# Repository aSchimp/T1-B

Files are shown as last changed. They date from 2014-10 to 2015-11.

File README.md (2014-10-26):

T1-B
====

T1-B = Turtle Bot 1

Installation
====

This *must* be run on a BeagleBone Black running the Debian operating system.  Get the latest image from: http://beagleboard.org/latest-images. The image used for testing was dated 2014-04-23. To check the version installed use

````
cat /boot/uboot/ID.txt
````

Make sure you can establish an SSH connection to the BeagleBone Black. Also make sure that the BBB has a persistant internet connection, either through an ethernet connection or through a USB connection to your computer.

### Setting up a persistant USB internet connection

The steps below are for Windows.

* Open the control panel, and search for "network connections" in the search box. Click "View Network Connections" in the results.
* Right-click the internet connection to share with the BeagleBone Black and select Properties. Navigate to the Sharing tab.
* Select the option to "Allow other network users to connect through this computer's Internet connection"
* Select the BeagleBone Black's network connection from the dropdown and then click OK.
* Now go back to Network Connections and right click the BeagleBone Black's network connection, and select Properties.
* Click "Internet Protocol Version 4 (TCP/IPv4)" in the list and select Properties
* Select the options to "Obtain an IP address automatically" and "obtain DNS server address automatically", and click OK

On the BeagleBone Black run the following commands

````
route add default gw 192.168.7.1
echo "nameserver 8.8.8.8" >> /etc/resolv.conf
````

Test the connection by running `ping google.com`.

Run the following command.

````
nano /opt/scripts/boot/am335x_evm.sh
````

Scroll down until you see the following lines

````
/sbin/ifconfig usb0 192.168.7.2 netmask 255.255.255.252
/usr/sbin/udhcpd -S /etc/udhcpd.conf
````

Immediately after those lines, add the following:

````
/sbin/route add default gw 192.168.7.1 metric 1
````

While you're editing that file, add the following line as well (beneath the line just added). This will allow the WiFi connection which will be setup by the installation script to work on startup. Replace 192.168.1.1 with the IP address of your router. You can find this by running `ipconfig` from a command prompt in Windows. Look for the default gateway for the wireless network connection.

````
/sbin/route add default gw 192.168.1.1 metric 2
````

Thanks to [Carl Lance](http://lanceme.blogspot.com/2013/06/windows-7-internet-sharing-for.html) for the pointers on getting this to work.

### Optionally Disable HDMI

TODO: Add an explanation here

https://learn.adafruit.com/setting-up-wifi-with-beaglebone-black/hardware

### Install Git

````
ntpdate -b -s -u pool.ntp.org
apt-get update && apt-get install git
````

### Install T1-B Software

Shutdown the BBB and plug in the USB wifi adapter. Use a WiFi adapter from [this list](http://www.elinux.org/Beagleboard:BeagleBoneBlack#WIFI_Adapters) for best results. The T1-B installation script has only been tested with the [NETGEAR N150 Wi-Fi USB Adapter (WNA1100)](http://www.amazon.com/gp/product/B0036R9XRU/ref=oh_aui_detailpage_o02_s00?ie=UTF8&psc=1). Turn the device back on.

Clone this repository into {TODO: determine best directory} using the following command.

````
cd {TODO: put directory here}
git clone https://github.com/aschimp/t1-b
````

Place your WiFi network SSID and password into the settings.cfg file.

````
cd t1-b/setup
nano settings.cfg
````

Finally, run the install script. The system will reboot several times during the installation. Log messages after rebooting will be sent to the install_log.txt file in the t1-b/setup directory.

````
chmod +x *.sh
./install.sh
````

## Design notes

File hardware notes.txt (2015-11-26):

Fasteners for main circuit board
 - Nuts: DURATOOL   M2.5- HFST-Z100-  FULL NUT, STEEL, BZP, M2.5: http://www.newark.com/webapp/wcs/stores/servlet/ProductDisplay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
 - Top washers (between board and screw head): KEYSTONE     3114  FASTENERS, NYLON WASHER - external diameter: 4.75mm - inner diameter: 2.49mm - length: 0.81mm - http://www.newark.com/webapp/wcs/stores/servlet/ProductDisplay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
 - Spacer washers (between board and chassis): RAF ELECTRONIC HARDWARE  1124-8-N  SPACER, NYLON, 6.35MM X 6.35MM - inner diameter: 4.216MM: http://www.newark.com/webapp/wcs/stores/servlet/ProductDisplay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
 - Screws: DURATOOL     M2.512 PRSTMCZ100-  SCREW, POZI PAN, STEEL, M2.5X12: http://www.newark.com/webapp/wcs/stores/servlet/ProductDisplay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

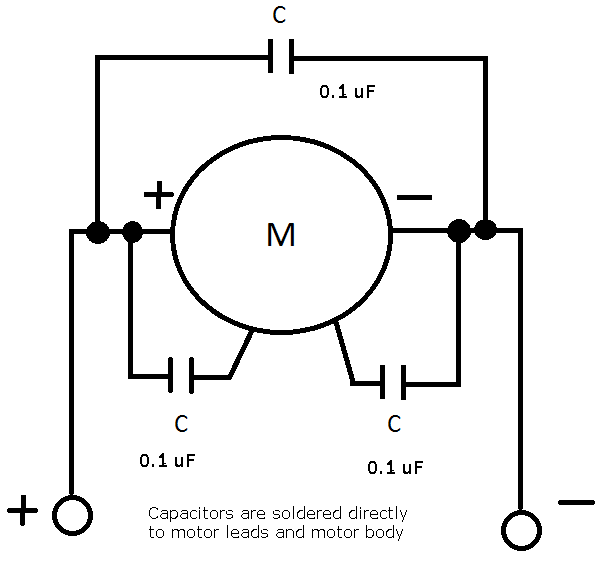
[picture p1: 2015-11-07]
eagle-t1-b/drive_motor.png

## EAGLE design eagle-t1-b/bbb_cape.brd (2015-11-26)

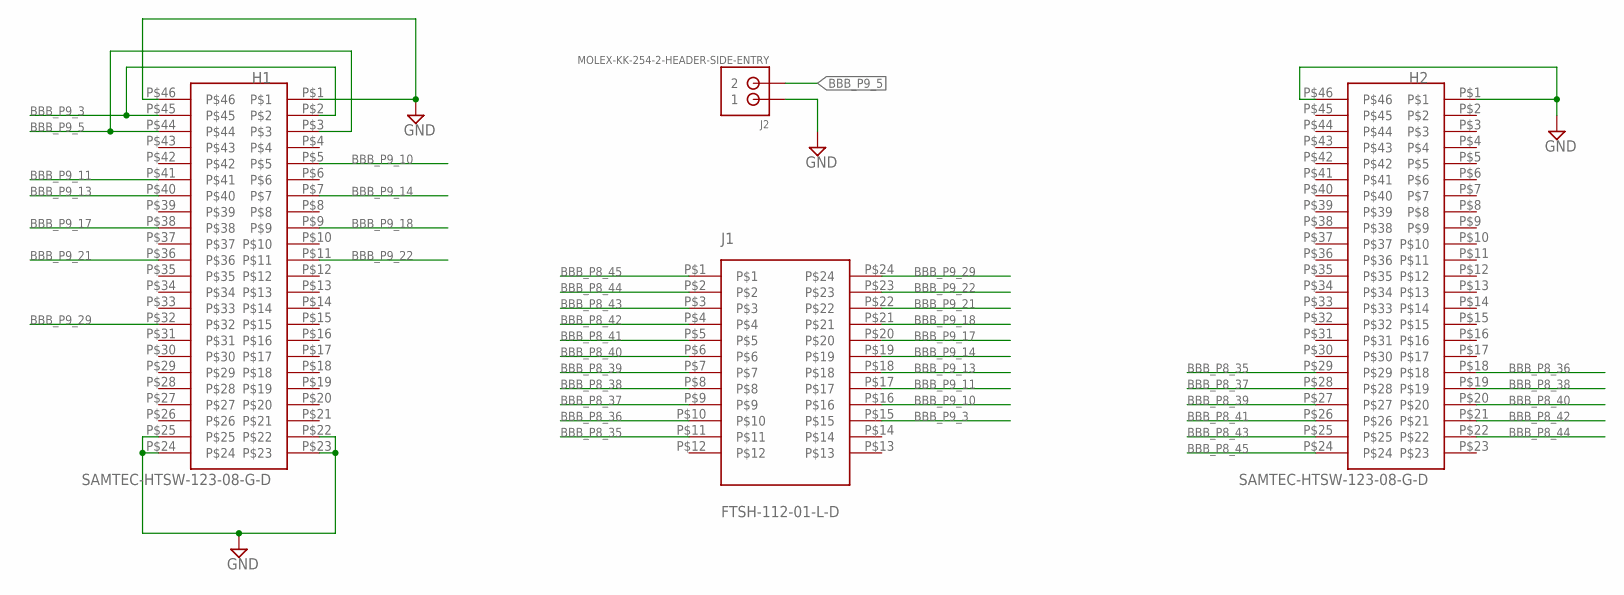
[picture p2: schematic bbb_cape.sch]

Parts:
H1, H2: SAMTEC-HTSW-123-08-G-D; HEADER-2X23-0.1-INCH
J1: FTSH-112-01-L-D
J2: MOLEX-KK-254-2-HEADER-SIDE-ENTRY

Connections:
BBB_P8_35: H2.P$29, J1.P$11
BBB_P8_36: H2.P$18, J1.P$10
BBB_P8_37: H2.P$28, J1.P$9
BBB_P8_38: H2.P$19, J1.P$8
BBB_P8_39: H2.P$27, J1.P$7
BBB_P8_40: H2.P$20, J1.P$6
BBB_P8_41: H2.P$26, J1.P$5
BBB_P8_42: H2.P$21, J1.P$4
BBB_P8_43: H2.P$25, J1.P$3
BBB_P8_44: H2.P$22, J1.P$2
BBB_P8_45: H2.P$24, J1.P$1
BBB_P9_3: H1.P$2, H1.P$45, J1.P$15
BBB_P9_5: H1.P$3, H1.P$44, J2.P$2 (2)
BBB_P9_10: H1.P$5, J1.P$16
BBB_P9_11: H1.P$41, J1.P$17
BBB_P9_13: H1.P$40, J1.P$18
BBB_P9_14: H1.P$7, J1.P$19
BBB_P9_17: H1.P$38, J1.P$20
BBB_P9_18: H1.P$9, J1.P$21
BBB_P9_21: H1.P$36, J1.P$22
BBB_P9_22: H1.P$11, J1.P$23
BBB_P9_29: H1.P$32, J1.P$24
GND: H1.P$1, H1.P$22, H1.P$23, H1.P$24, H1.P$25, H1.P$46, H2.P$1, H2.P$46, J2.P$1 (1)

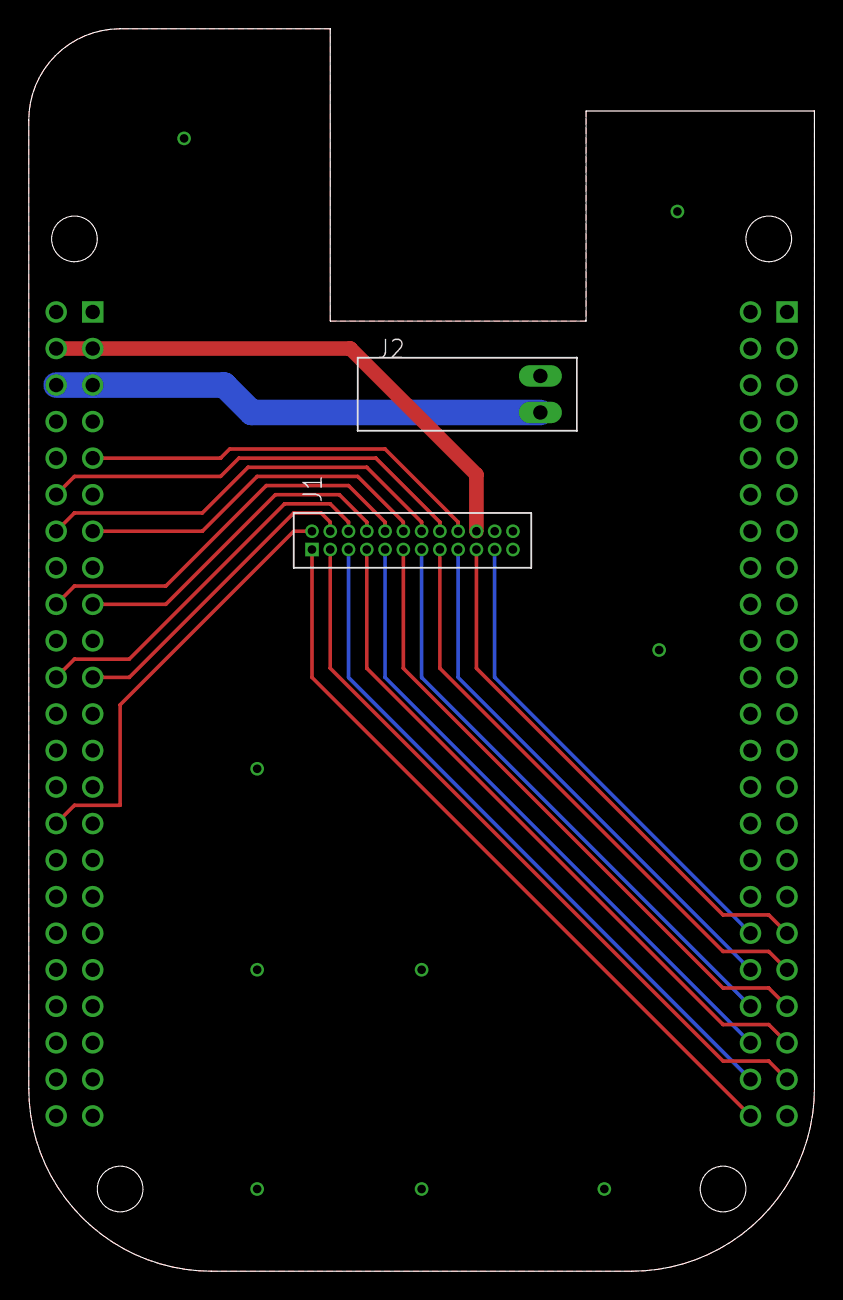
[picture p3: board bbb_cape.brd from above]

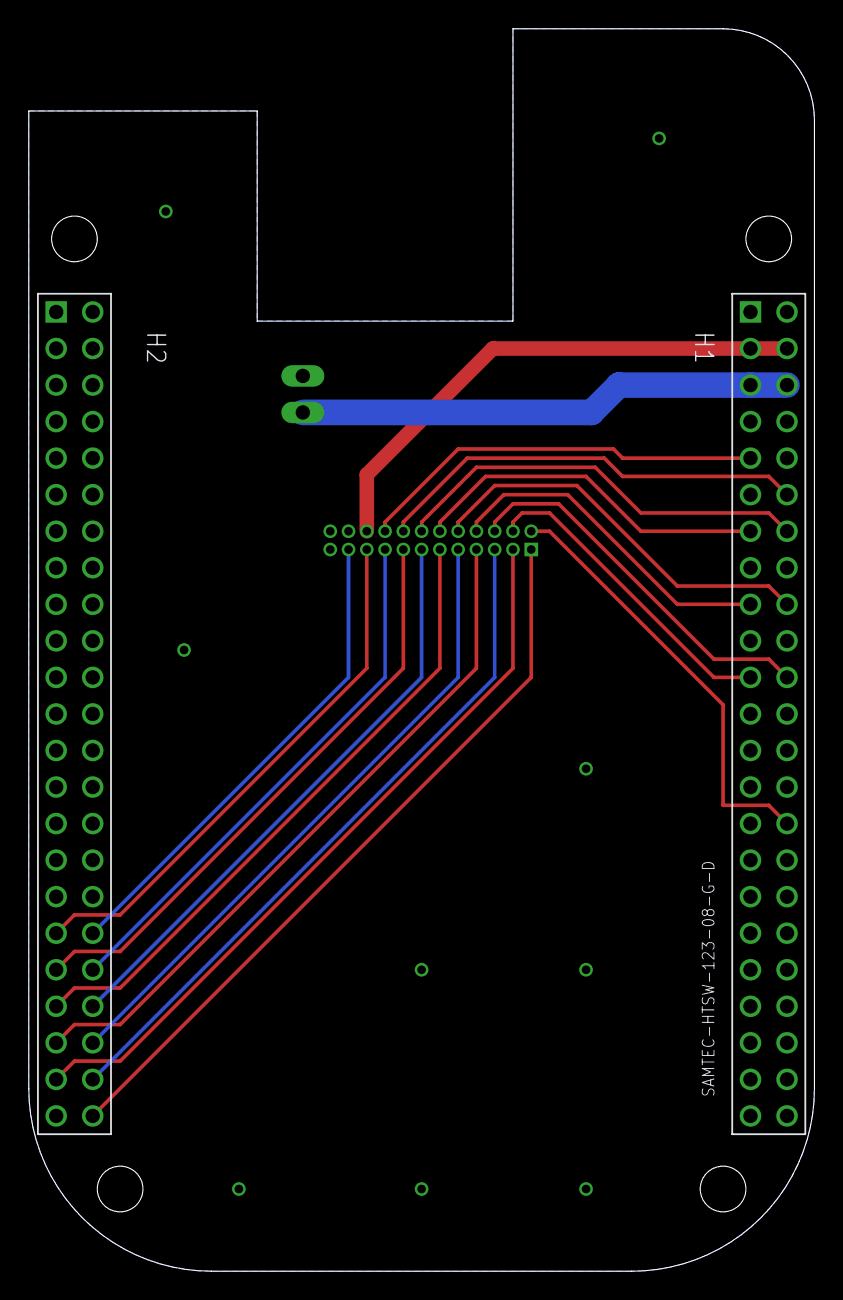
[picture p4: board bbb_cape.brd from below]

Board: 2 copper layers, 54.6 x 86.4 mm, 4 parts (2 on the bottom side), 23 nets.

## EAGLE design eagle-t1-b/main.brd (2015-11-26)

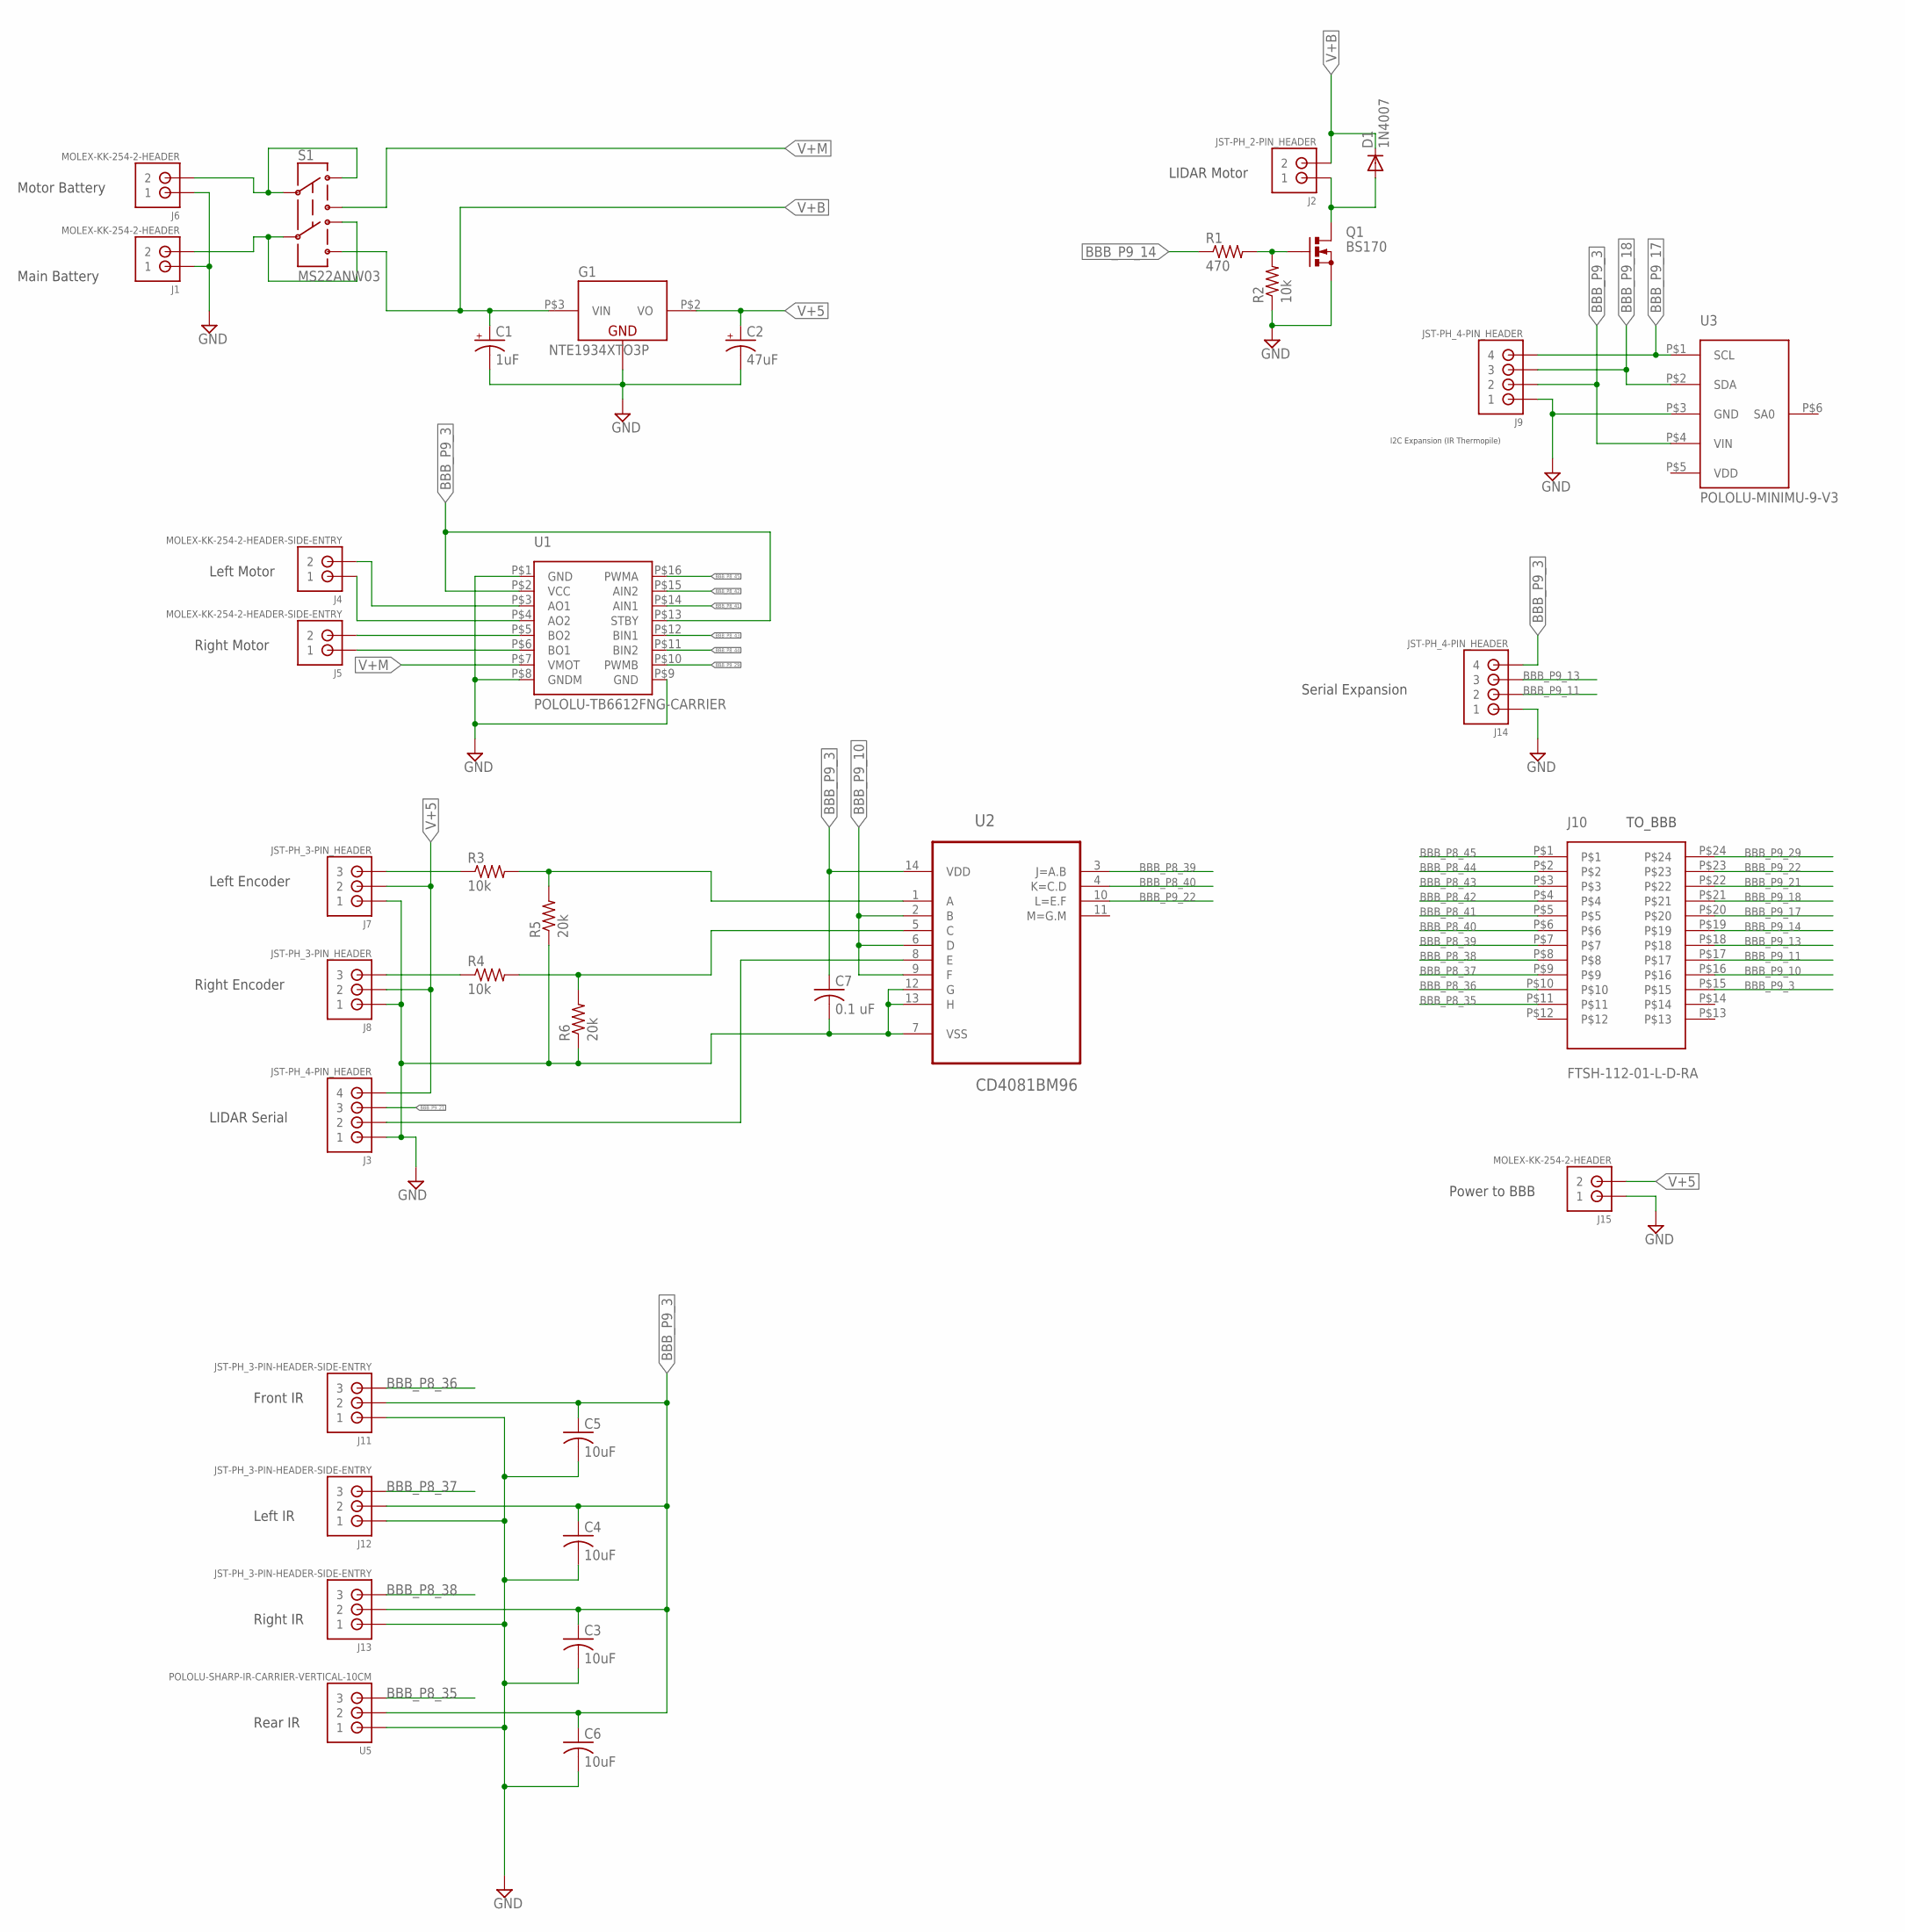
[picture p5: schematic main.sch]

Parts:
C1: 1uF; PANASONIC_B
C2: 47uF; PANASONIC_C
C3, C4, C5, C6: 10uF; C0603
C7: 0.1 uF; C0603
D1: 1N4007; DO41-10
G1: NTE1934XTO3P; TO3P
J1, J6, J15: MOLEX-KK-254-2-HEADER
J2: JST-PH_2-PIN_HEADER; JST_B2B-PH_HEADER
J3, J9, J14: JST-PH_4-PIN_HEADER; JST_B4B-PH_HEADER
J4, J5: MOLEX-KK-254-2-HEADER-SIDE-ENTRY
J7, J8: JST-PH_3-PIN_HEADER; JST_B3B-PH_HEADER
J10: FTSH-112-01-L-D-RA
J11, J12, J13: JST-PH_3-PIN-HEADER-SIDE-ENTRY; JST-S3B-PH-K-S
Q1: BS170; SOT54E
R1: 470; R0402
R2, R3, R4: 10k; R0402
R5, R6: 20k; R0402
S1: MS22ANW03; SWITCH-DPDT-NKK-MS22ANW03
U1: POLOLU-TB6612FNG-CARRIER
U2: CD4081BM96; SO14
U3: POLOLU-MINIMU-9-V3
U5: POLOLU-SHARP-IR-CARRIER-VERTICAL-10CM; POLOLU-SHARP-IR-CARRIER-VERTICAL-GP2Y0D8**Z0F

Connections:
BBB_P8_35: J10.P$11, U5.P$3 (3)
BBB_P8_36: J10.P$10, J11.P$3 (3)
BBB_P8_37: J10.P$9, J12.P$3 (3)
BBB_P8_38: J10.P$8, J13.P$3 (3)
BBB_P8_39: J10.P$7, U2.3 (J=A.B)
BBB_P8_39_AND_INPUT: R3.2, R5.2, U2.1 (A)
BBB_P8_40: J10.P$6, U2.4 (K=C.D)
BBB_P8_40_AND_INPUT: R4.2, R6.2, U2.5 (C)
BBB_P8_41: J10.P$5, U1.P$14 (AIN1)
BBB_P8_42: J10.P$4, U1.P$15 (AIN2)
BBB_P8_43: J10.P$3, U1.P$12 (BIN1)
BBB_P8_44: J10.P$2, U1.P$11 (BIN2)
BBB_P8_45: J10.P$1, U1.P$16 (PWMA)
BBB_P9_3: C3.1, C4.1, C5.1, C6.1, C7.1, J9.P2 (2), J10.P$15, J11.P$2 (2), J12.P$2 (2), J13.P$2 (2), J14.P4 (4), U1.P$2 (VCC), U1.P$13 (STBY), U2.14 (VDD), U3.P$4 (VIN), U5.P$2 (2)
BBB_P9_10: J10.P$16, U2.2 (B), U2.6 (D), U2.9 (F)
BBB_P9_11: J10.P$17, J14.P2 (2)
BBB_P9_13: J10.P$18, J14.P3 (3)
BBB_P9_14: J10.P$19, R1.1
BBB_P9_17: J9.P4 (4), J10.P$20, U3.P$1 (SCL)
BBB_P9_18: J9.P3 (3), J10.P$21, U3.P$2 (SDA)
BBB_P9_21: J3.P3 (3), J10.P$22
BBB_P9_22: J10.P$23, U2.10 (L=E.F)
BBB_P9_29: J10.P$24, U1.P$10 (PWMB)
GND: C1.-, C2.-, C3.2, C4.2, C5.2, C6.2, C7.2, G1.P$1 (GND), J1.P$1 (1), J3.P1 (1), J6.P$1 (1), J7.P1 (1), J8.P1 (1), J9.P1 (1), J11.P$1 (1), J12.P$1 (1), J13.P$1 (1), J14.P1 (1), J15.P$1 (1), Q1.S, R2.1, R5.1, R6.1, U1.P$1 (GND), U1.P$8 (GNDM), U1.P$9 (GND), U2.7 (VSS), U2.12 (G), U2.13 (H), U3.P$3 (GND), U5.P$1 (1)
unnamed: Q1.G, R1.2, R2.2
unnamed: D1.A, J2.P1 (1), Q1.D
unnamed: J5.P$1 (1), U1.P$6 (BO1)
unnamed: J5.P$2 (2), U1.P$5 (BO2)
unnamed: J4.P$1 (1), U1.P$4 (AO2)
unnamed: J4.P$2 (2), U1.P$3 (AO1)
unnamed: J7.P3 (3), R3.1
unnamed: J6.P$2 (2), S1.P$1 (1), S1.P$2 (2)
unnamed: J1.P$2 (2), S1.P$4 (4), S1.P$5 (5)
unnamed: J8.P3 (3), R4.1
unnamed: J3.P2 (2), U2.8 (E)
V+5: C2.+, G1.P$2 (VO), J3.P4 (4), J7.P2 (2), J8.P2 (2), J15.P$2 (2)
V+B: C1.+, D1.C, G1.P$3 (VIN), J2.P2 (2), S1.P$6 (6)
V+M: S1.P$3 (3), U1.P$7 (VMOT)
VDD: U3.P$5 (VDD)

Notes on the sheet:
Left Motor
Right Motor
Motor Battery
Main Battery
Left Encoder
Right Encoder
LIDAR Serial
LIDAR Motor
I2C Expansion (IR Thermopile)
TO_BBB
Serial Expansion
Front IR
Left IR
Right IR
Rear IR
Power to BBB

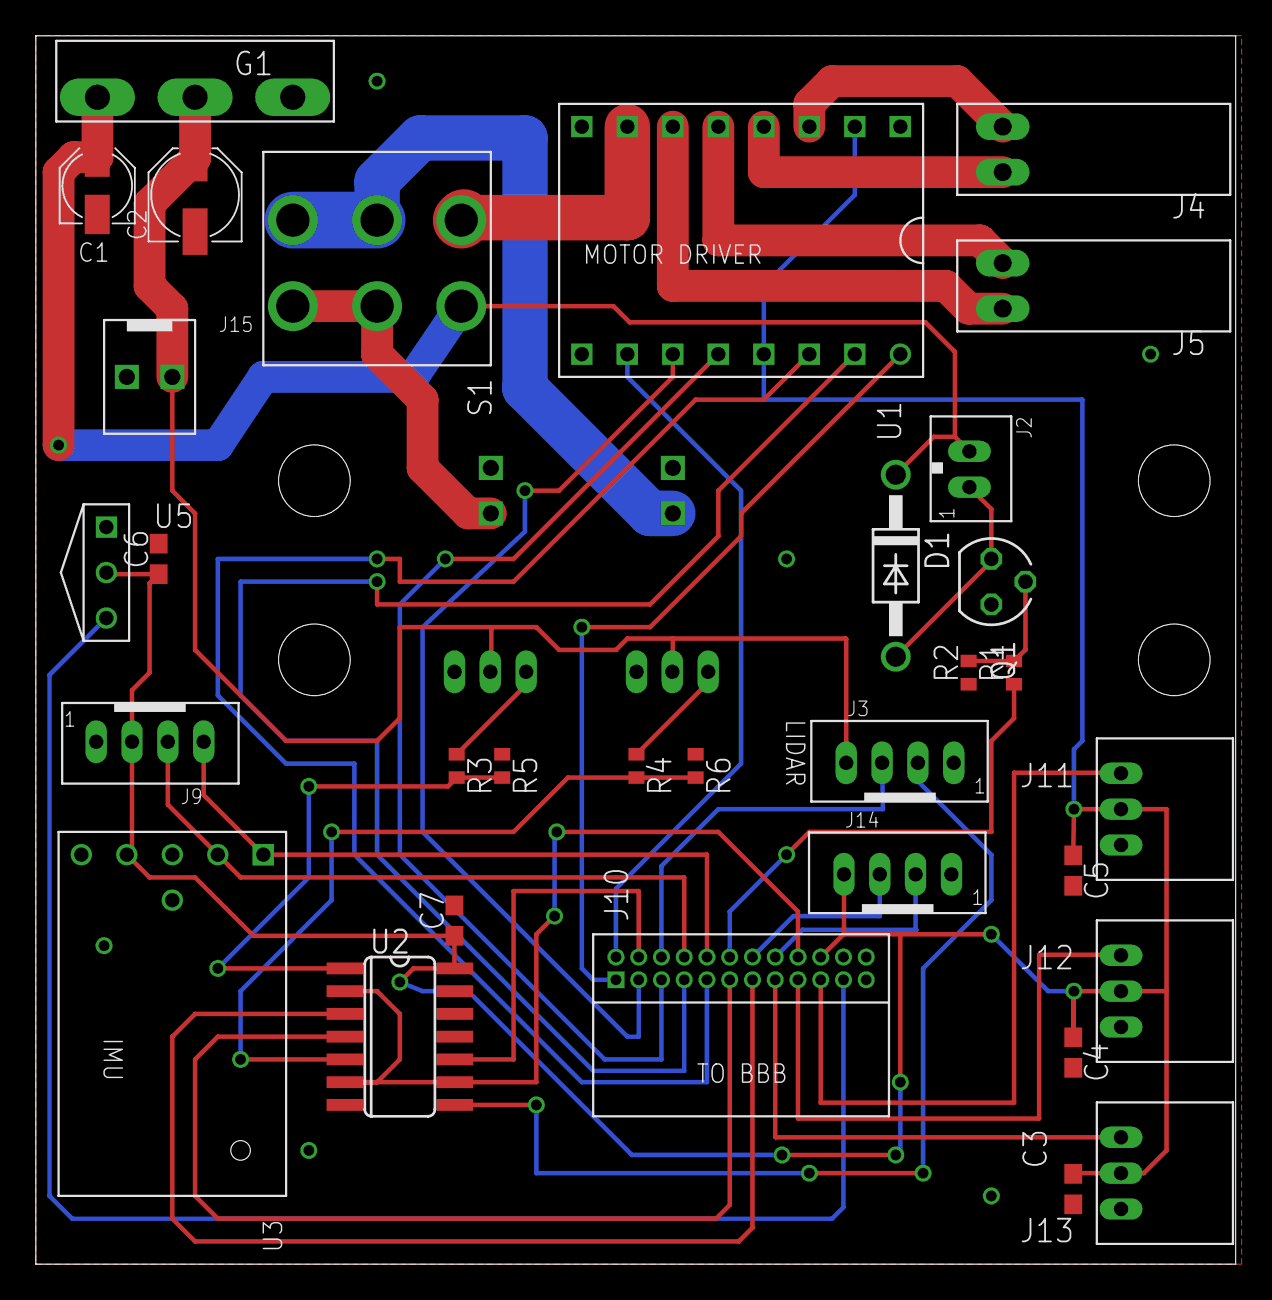
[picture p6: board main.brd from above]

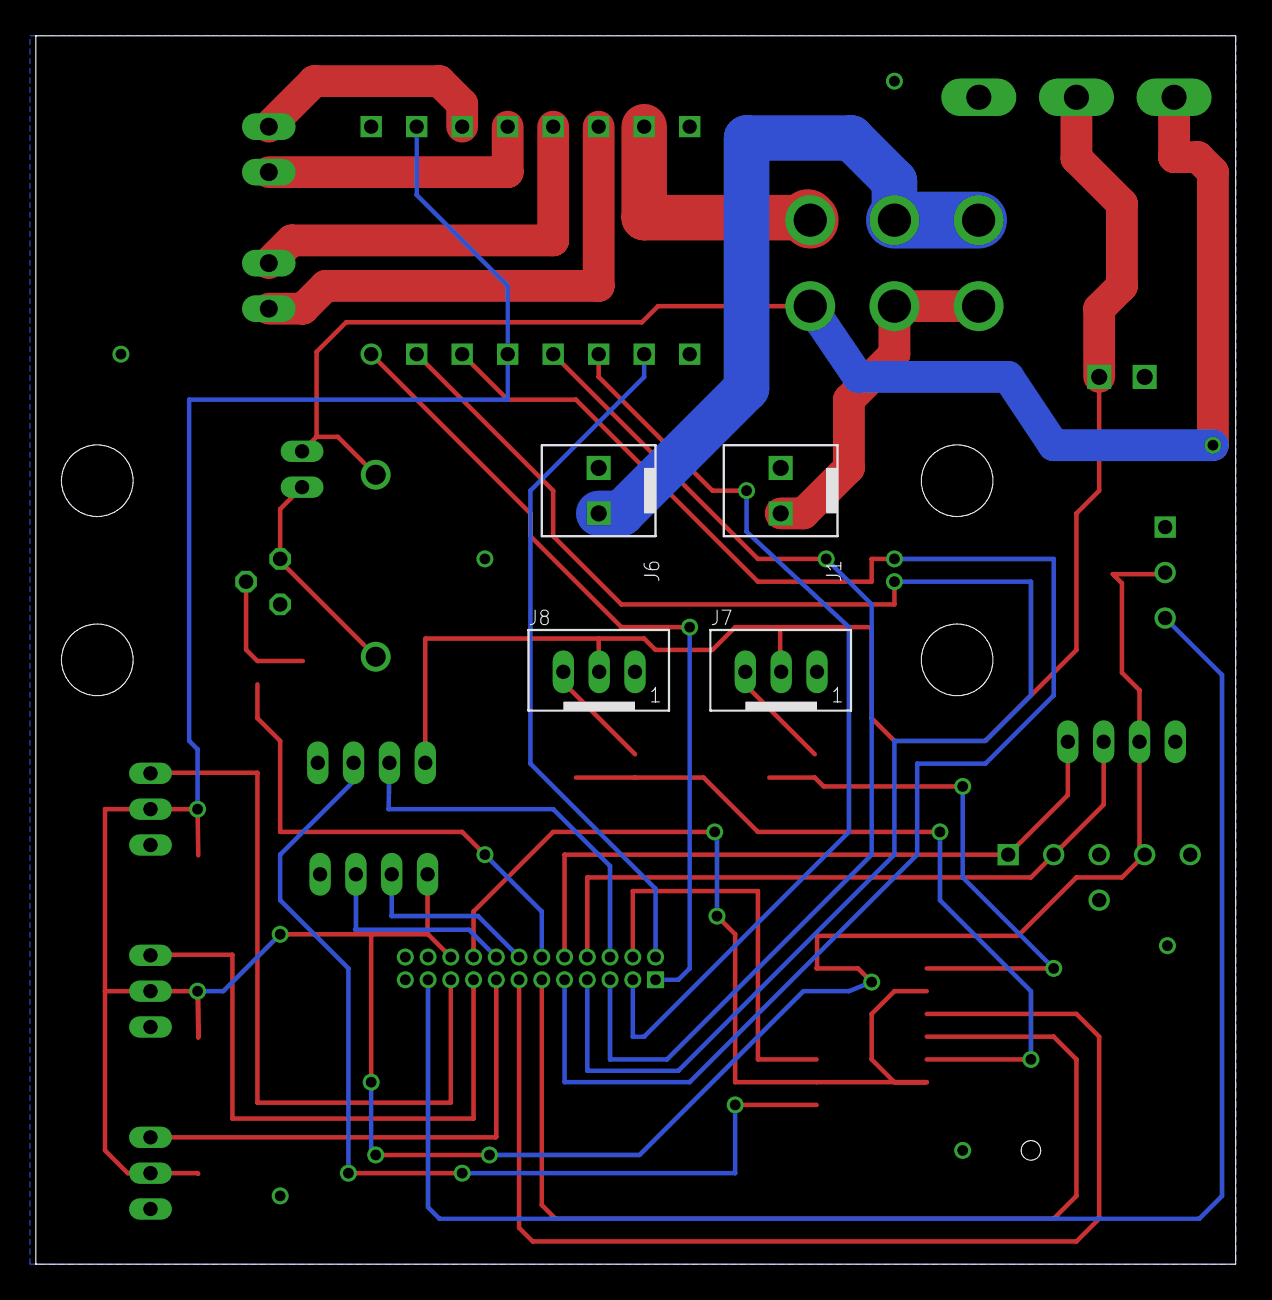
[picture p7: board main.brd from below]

Board: 2 copper layers, 67.0 x 68.6 mm, 36 parts (4 on the bottom side), 38 nets.

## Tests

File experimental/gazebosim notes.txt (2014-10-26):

upgraded to virtualbox 4.3.10 (upgraded guest additions in manager, then in vm)
http://askubuntu.com/a/22745/162919

add vboxvideo to /etc/modules file

sudo apt-get install mesa-utils, then run glxinfo

export LIBGL_ALWAYS_SOFTWARE=1  ------ this works, but is slow

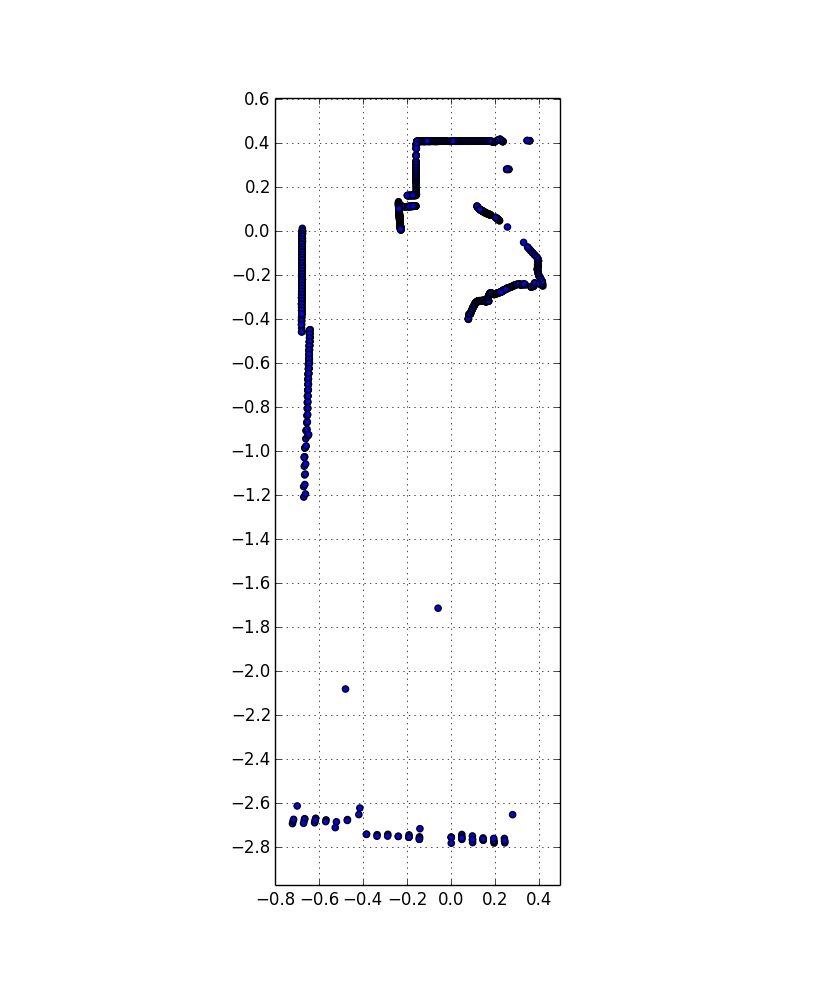
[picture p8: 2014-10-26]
experimental/first_lidar_test/lidar_graph_1.png

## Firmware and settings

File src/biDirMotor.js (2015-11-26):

var fs = require('fs');
var path = require('path');
var glob = require('glob');
var ioHelper = require('./ioHelper.js');

// constants
var dutyCycleMin = 0.1;
var dutyCycleMax = 0.7;
var period = 1000000;

// bi-directional motor
function BiDirMotor(pwmPath, gpio1Path, gpio2Path) {
    var self = this;
    self._pwmPath = pwmPath;
    self._gpio1Path = gpio1Path;
    self._gpio2Path = gpio2Path;

    self.setRotation(0);
}

// The value should be a number between -1 and 1. Negative values cause CW rotation and positive values cause CCW rotation. A value of 0 stops the motor. The absolute value controls the pwm duty cycle (speed).
BiDirMotor.prototype.setRotation = function(value) {
    var self = this;

    if (value === 0) {
        ioHelper.setGpioSignal(self._gpio1Path, 0);
        ioHelper.setGpioSignal(self._gpio2Path, 0);
        ioHelper.sendPwmCommand(self._pwmPath, 'run', '0');
        return;
    }

    var duty = Math.round((1 - Math.min(Math.max(Math.abs(value), dutyCycleMin), dutyCycleMax)) * period);
    ioHelper.sendPwmCommand(self._pwmPath, 'period', period.toString());
    ioHelper.sendPwmCommand(self._pwmPath, 'duty', duty.toString());
    ioHelper.sendPwmCommand(self._pwmPath, 'run', '1');

    if (value > 0) {
        ioHelper.setGpioSignal(self._gpio1Path, 1);
        ioHelper.setGpioSignal(self._gpio2Path, 0);
    }
    else if (value < 0) {
        ioHelper.setGpioSignal(self._gpio1Path, 0);
        ioHelper.setGpioSignal(self._gpio2Path, 1);
    }
};

module.exports = BiDirMotor;

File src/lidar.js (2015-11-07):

var util = require('util');
var events = require('events');
var SerialPort = require("serialport").SerialPort;
var ioHelper = require('./ioHelper.js');

function LidarPacket(index, speed, dist1, dist2, dist3, dist4){
    this.index = index;
    this.speed = speed;
    this.dist1 = dist1;
    this.dist2 = dist2;
    this.dist3 = dist3;
    this.dist4 = dist4;
}

/**
 * Computes and returns the checksum as an int.
 * @param {Array} data - The data to compute the checksum for. Must be 20 bytes.
 * @return {Number} The checksum as an integer.
 */
var computeChecksum = function(data) {
    // group the data by word, little-endian
    var dataList = [];
    for (var i = 0; i < 10; i++){
        dataList.push(data[2*i] + (data[2*i+1]<<8));
    }

    // compute the checksum on 32 bits
    var chk32 = 0;
    dataList.forEach(function(item){
        chk32 = (chk32 << 1) + item;
    });

    // return a value wrapped around on 15 bits, and truncated to still fit into 15 bits
    var checksum = (chk32 & 0x7FFF) + (chk32 >> 15); // wrap around to fit into 15 bits
    checksum = checksum & 0x7FFF; // truncate to 15 bits
    return checksum;
};

/**
 * Gets the lidar distance reading from a 4 byte data section.
 * @param {Array} bytes - Buffer with 4 bytes of data.
 * @return {Number} The distance reading as an integer.
 */
var parsePacketDataSection = function(bytes) {
    // if the 8th bit of the byte 1 is set, the data is invalid; the 7th bit of byte 1 is a strength warning (varies with material sometimes) flag, but we are ignoring it for now
    if ((bytes[1] & 128) === 128)
        return -1;

    // check strength warning bit
    if ((bytes[1] & 64) === 64)
        return -2;

    // get distance from byte 0 and byte 1; byte 2 and byte 3 contain signal strength data, which we are ignoring for now
    return bytes[0] + ((bytes[1] & 63) << 8);
};

var parsePacket = function(bytes) {
    // first byte in the packet must be 0xFA
    if (bytes[0] != 0xFA)
        return null;

    // verify data via checksum
    if (computeChecksum(bytes.slice(0, 20)) !== (bytes[20] + (bytes[21] << 8)))
        return null;

    // packet index must be between 0xA0 and 0xF9
    var index = bytes[1];
    if (index < 0xA0 || index > 0xF9)
        return null;

    // adjust index to 0 based index
    index = index - 0xA0;

    // speed unit used by the LIDAR is in 64ths of an RPM; we want the speed in RPMs
    var speed = (bytes[2] + (bytes[3]<<8))/64.0;

    var distances = [];
    for (var i = 1; i < 5; i++)
        distances.push(parsePacketDataSection(bytes.slice(4*i, 4*i+4)));

    return new LidarPacket(index, speed, distances[0], distances[1], distances[2], distances[3]);
};

function Lidar(serialPath, pwmPath) {
    var self = this;
    self._pwmPath = pwmPath;
    self._lidarStopped = true;
    self._pwmDuty = 710000;
    self._serialPort = new SerialPort(serialPath, {
        baudrate: 115200
    });

    self._serialPort.on("open", function () {
        console.log('serial port to lidar is open');

        var currentPacketData = [];
        self._serialPort.on('data', function(data) {
            //console.log('data received from lidar: ' + data.toString('hex'));
            self.emit('raw data', data);

            for (var i = 0; i < data.length; i++) {
                var b = data[i];

                // if we're starting a new packet, but the current byte doesn't mark the beginning of the packet, skip it
                if (currentPacketData.length === 0 && b != 0xFA)
                    continue;

                currentPacketData.push(b);

                if (currentPacketData.length === 22) {
                    var packet = parsePacket(currentPacketData);
                    if (packet === null) {
                        // packet was invalid; check for 0xFA packet start marker in the last packet, as sometimes some bytes are dropped and the next packet is already started
                        var nextIndex = currentPacketData.slice(1).indexOf(0xFA) + 1;
                        if (nextIndex > 0)
                            currentPacketData = currentPacketData.slice(nextIndex);
                        else
                            currentPacketData = [];
                    }
                    else {
                        self.emit('packet', packet);

                        // reset currentPacketData
                        currentPacketData = [];
                    }
                }
            }
        });
    });

    var targetRPM = 240;
    var lastRPM = 0
    var rpmAdjustInProgress = false;
    self.on('packet', function(packet) {

        if (packet.index != 0 || self._lidarStopped){
            return;
        }

        var rpm = packet.speed;
        var prevRPM = 0;

        if (rpm > 100 && (rpm < targetRPM - 5 || rpm > targetRPM + 5) && lastRPM > 0 && Math.abs(rpm - lastRPM) < 3 && !rpmAdjustInProgress) {
            var deltaRPM = targetRPM - rpm;
            var deltaDuty = Math.round((deltaRPM / rpm) * self._pwmDuty * 0.5);

            self._pwmDuty -= deltaDuty;
            ioHelper.sendPwmCommand(self._pwmPath, 'duty', self._pwmDuty.toString());

            rpmAdjustInProgress = true;
            setTimeout(function(){ rpmAdjustInProgress = false; }, 3000);

            console.log('Changed pwm duty to: ' + self._pwmDuty);
            console.log('Current rpms: ' + rpm);
        }

        lastRPM = rpm;

        if (rpm < 100) {
            lastRPMs = 0;
        }
    });
}

// Inherit the EventEmitter - this line must be before prototype declarations
util.inherits(Lidar, events.EventEmitter);

// turns on the lidar motor
Lidar.prototype.start = function () {
    var self = this;

    console.log('Lidar starting.');

    if (self._pwmDuty > 1000000) {
        self._pwmDuty = 380000;
    }

    ioHelper.sendPwmCommand(self._pwmPath, 'period', '1000000');
    ioHelper.sendPwmCommand(self._pwmPath, 'duty', self._pwmDuty.toString());
    ioHelper.sendPwmCommand(self._pwmPath, 'run', '1');

    self._lidarStopped = false;
};

// turns off the lidar motor
Lidar.prototype.stop = function () {
    var self = this;

    console.log('Lidar stopping.');

    ioHelper.sendPwmCommand(self._pwmPath, 'run', '0');

    self._lidarStopped = true;
};

module.exports = Lidar;

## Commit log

2014-10-26 Added installation scripts (not finished yet) and python script for reading lidar data (also not finished yet
    [settings.cfg]
2015-10-18 Transferring code from bbb-sockets-test to jump-start T1-B's code.
2015-10-25 Added schematic for main board.
    [main.sch]
2015-10-28 Added intitialization script for right drive encoder and infrared proximity sensor input pins.
2015-10-29 Adding i2c nodejs package.
2015-10-30 Switching from i2c to i2c-bus
2015-10-30 Added init script for IMU I2C device tree overlay.
2015-11-01 Increased default pwm duty cycle for lidar motor now that it is being powered from 9.6 volts
2015-11-07 Finished main board schematic and pcb layout.
    [main.brd, main.sch]
2015-11-26 Finalized circuit board designs.
    [bbb_cape.brd, bbb_cape.sch, main.brd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]
2015-11-26 Reversing motor rotation.
